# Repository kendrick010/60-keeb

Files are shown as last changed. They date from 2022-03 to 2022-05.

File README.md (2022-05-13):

# 60-keeb
> A 60% keyboard because why not.

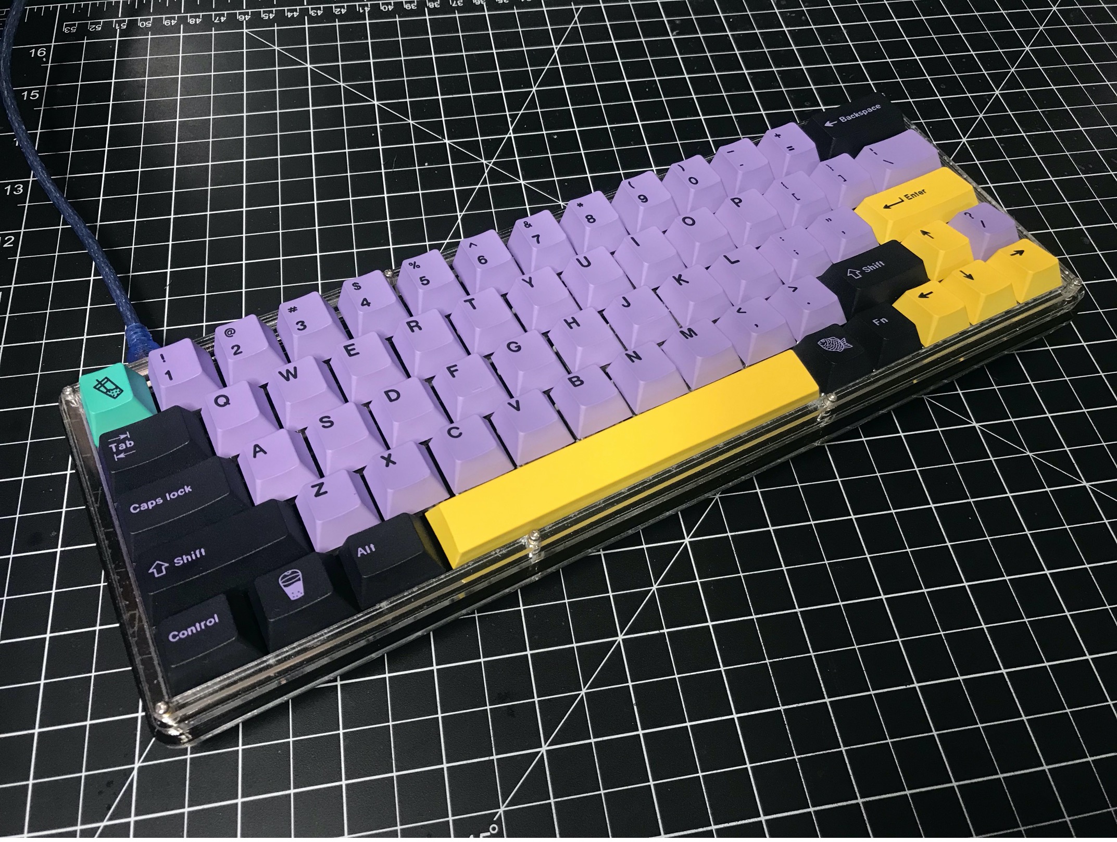
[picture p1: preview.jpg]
60-keeb


## How To...
Stack Order:
- plate_1 (top most)
- plate_2
- plate_3 (switch plate)
- plate_4
- plate_5
- plate_6 (bottom most)

## BOM
| Component | Vendor | Quantity|
| --- | --- | --- |
| PCB | -------- | 1 |
| ATMEGA32U4 | [Digikey](https://www.digikey.com/en/products/detail/microchip-technology/ATMEGA32U4RC-MUR/2507985) | 1 |
| USB Mini B Port | [Digikey](https://www.digikey.com/en/products/detail/edac-inc/690-005-299-043/4312191) | 1 |
| Tactile SMD Switch | [Digikey](https://www.digikey.com/en/products/detail/e-switch/TL3342F160QG-TR/379004) | 1 |
| 1N4148 SMD Diode | [Digikey](https://www.digikey.com/en/products/detail/smc-diode-solutions/1N4148WTR/6022450) | 63 |
| 16MHz SMD Cystal | [Digikey](https://www.digikey.com/en/products/detail/ecs-inc./ECS-160-12-33-AGM-TR/9648950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) | 1 |
| 22Ω SMD Resistor | [Digikey](https://www.digikey.com/en/products/detail/stackpole-electronics-inc/RMCF0805JT22R0/1942533) | 2 |
| 10kΩ SMD Resistor | [Digikey](https://www.digikey.com/en/products/detail/stackpole-electronics-inc/RMCF0805JT10K0/1942577) | 2 |
| 0.1uF Ceramic SMD Capacitor | [Digikey](https://www.digikey.com/en/products/detail/kyocera-avx/08055F104K4T2A/1024871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) | 4 |
| 1uF Ceramic SMD Capacitor | [Digikey](https://www.digikey.com/en/products/detail/yageo/CC0805KKX7R8BB105/2833621) | 1 |
| 4.7uF Ceramic SMD Capacitor | [Digikey](https://www.digikey.com/en/products/detail/samsung-electro-mechanics/CL21A475KAQNNNE/3886902) | 1 |
| 22pF Ceramic SMD Capacitor | [Digikey](https://www.digikey.com/en/products/detail/kemet/C0805C220J5GACTU/411388) | 2 |
| M2x16mm Standoffs | [Amazon](https://www.amazon.com/dp/B07768Q7YS?psc=1&ref=ppx_yo2ov_dt_b_product_details) | 8 |
| M2 Screws | [Amazon](https://www.amazon.com/dp/B07768Q7YS?psc=1&ref=ppx_yo2ov_dt_b_product_details) | 8 |

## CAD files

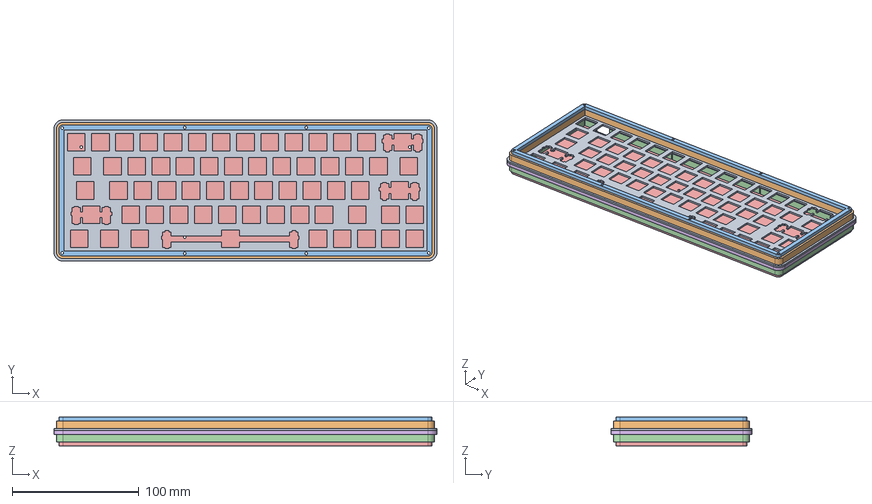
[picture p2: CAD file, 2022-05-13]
models/assembly.step
301.8 x 111.3 x 22.5 mm
plate_3
plate_2
plate_1
plate_5
plate_6
plate_4

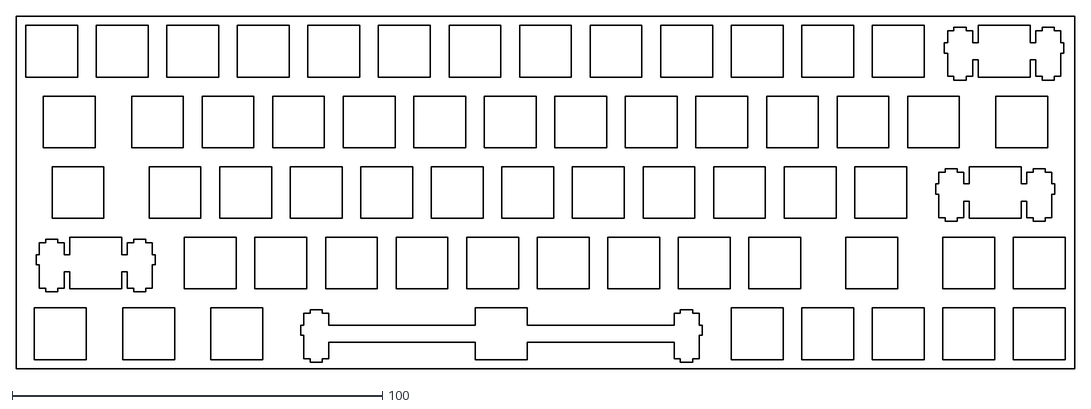
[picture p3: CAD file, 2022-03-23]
layout/60_layout.dxf
285.7 x 95.2

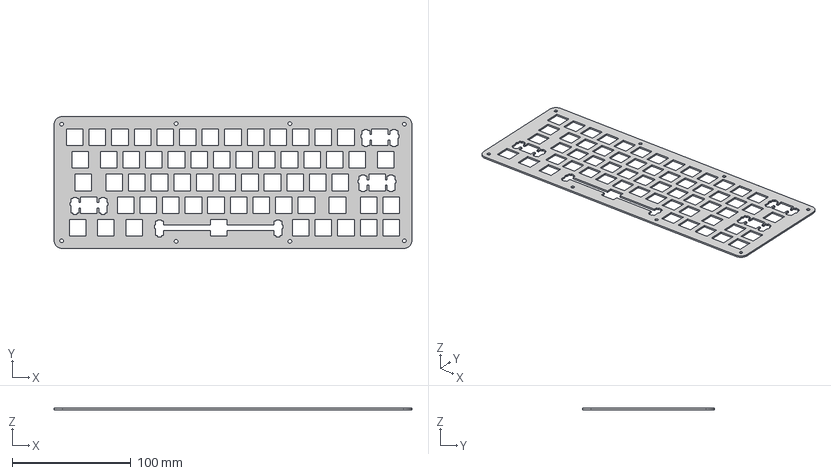
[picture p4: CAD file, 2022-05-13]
models/plate_3.step
301.7 x 111.2 x 1.50 mm

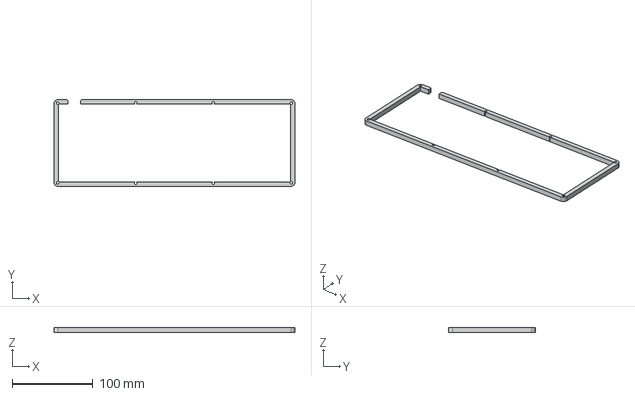
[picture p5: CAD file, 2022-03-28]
models/plate_5.step
297.8 x 107.2 x 6.00 mm

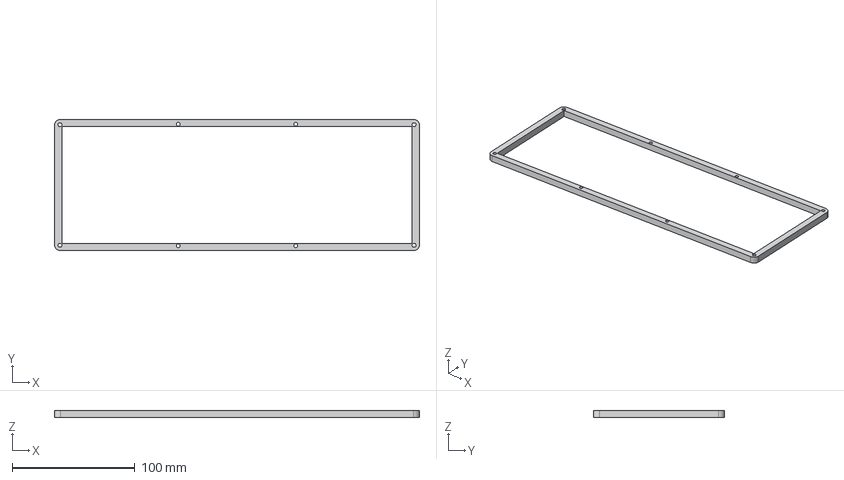
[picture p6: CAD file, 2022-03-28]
models/plate_2.step
297.8 x 107.2 x 6.00 mm

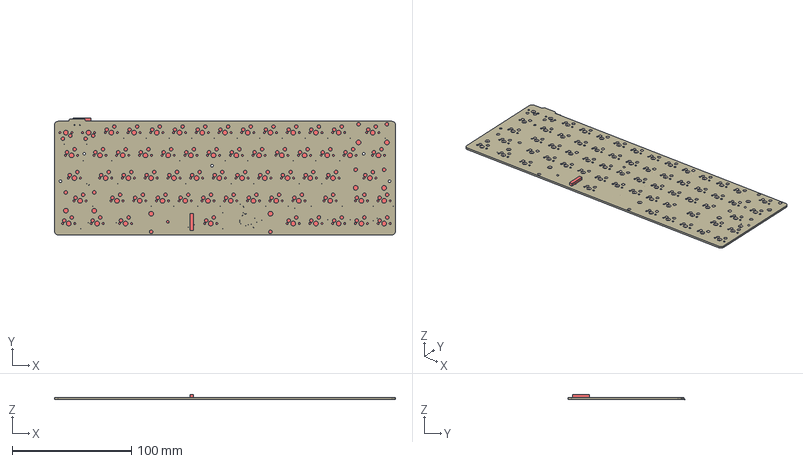
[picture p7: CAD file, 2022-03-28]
models/60_keyboard_PCB.step
285.8 x 97.9 x 4.24 mm
Board
1u
SOD-123 x 63
10k x 2
TACTILE
KEYSWITCH-PLAIN-MXHSPCB-1U x 59
KEYSWITCH-PLAIN-MXHSPCB-2U x 3
ATMEGA32U4
0.1u x 4
4.7u
22p x 2
CRYSTAL
KEYSWITCH-PLAIN-MXHSPCB-6.25U-FLIPPED
USB-CON
MA06-1

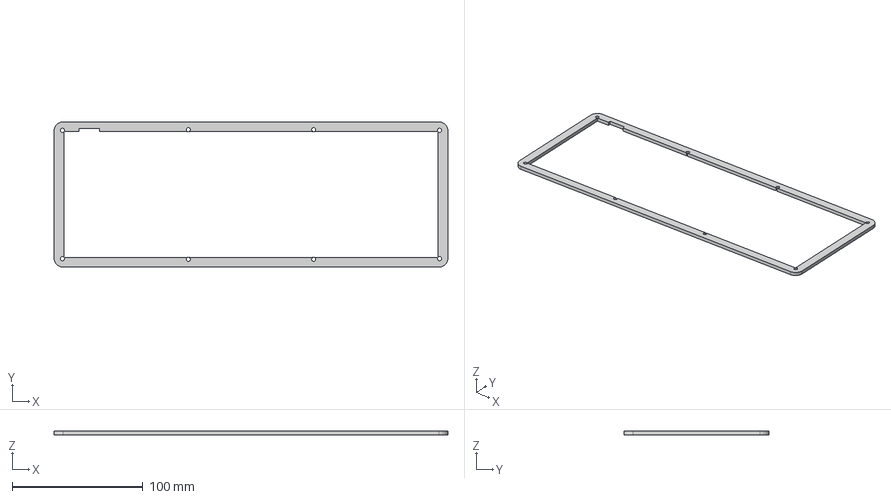
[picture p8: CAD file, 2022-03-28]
models/plate_4.step
301.8 x 111.2 x 3.00 mm

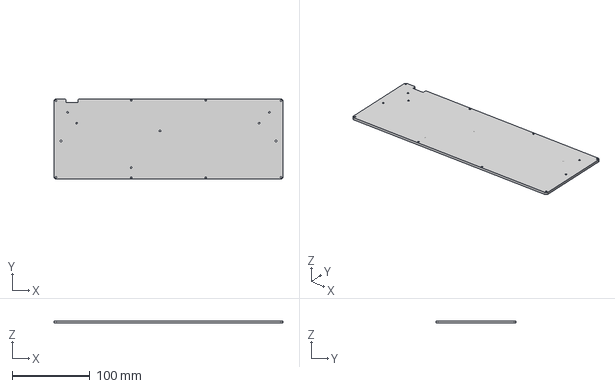
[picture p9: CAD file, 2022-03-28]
models/plate_6.step
293.8 x 103.3 x 3.00 mm

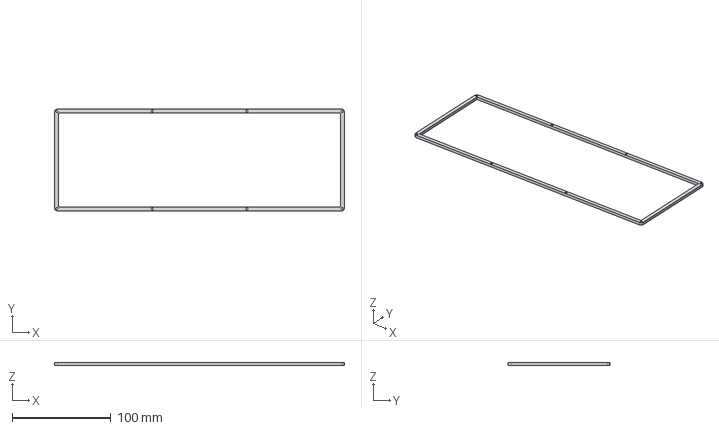
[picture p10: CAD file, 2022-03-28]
models/plate_1.step
293.8 x 103.3 x 3.00 mm

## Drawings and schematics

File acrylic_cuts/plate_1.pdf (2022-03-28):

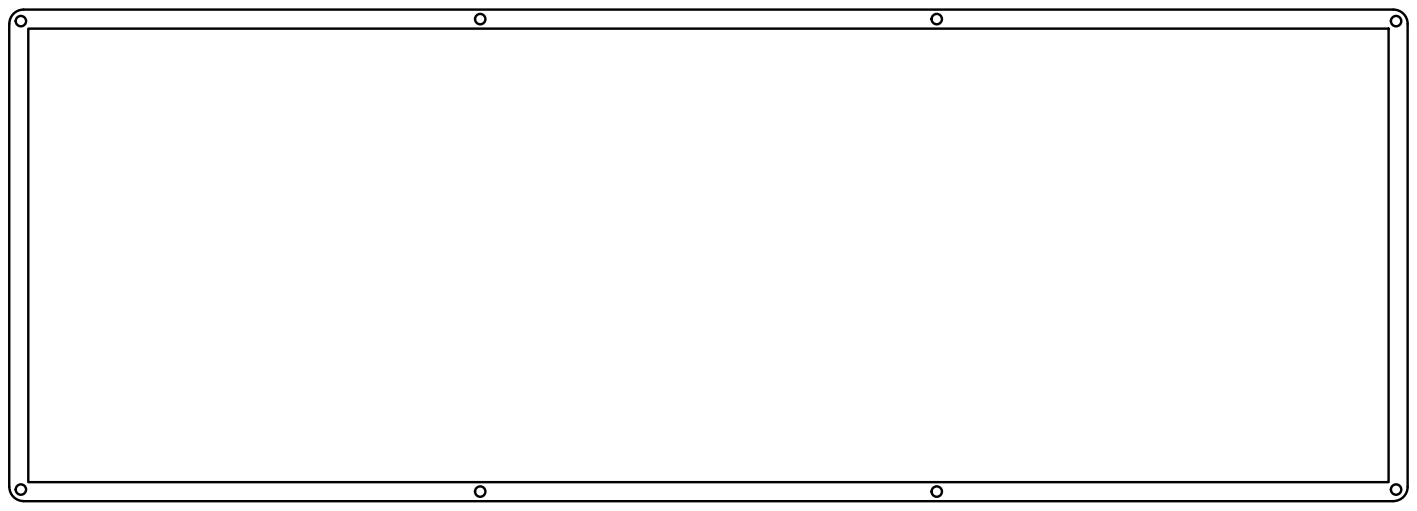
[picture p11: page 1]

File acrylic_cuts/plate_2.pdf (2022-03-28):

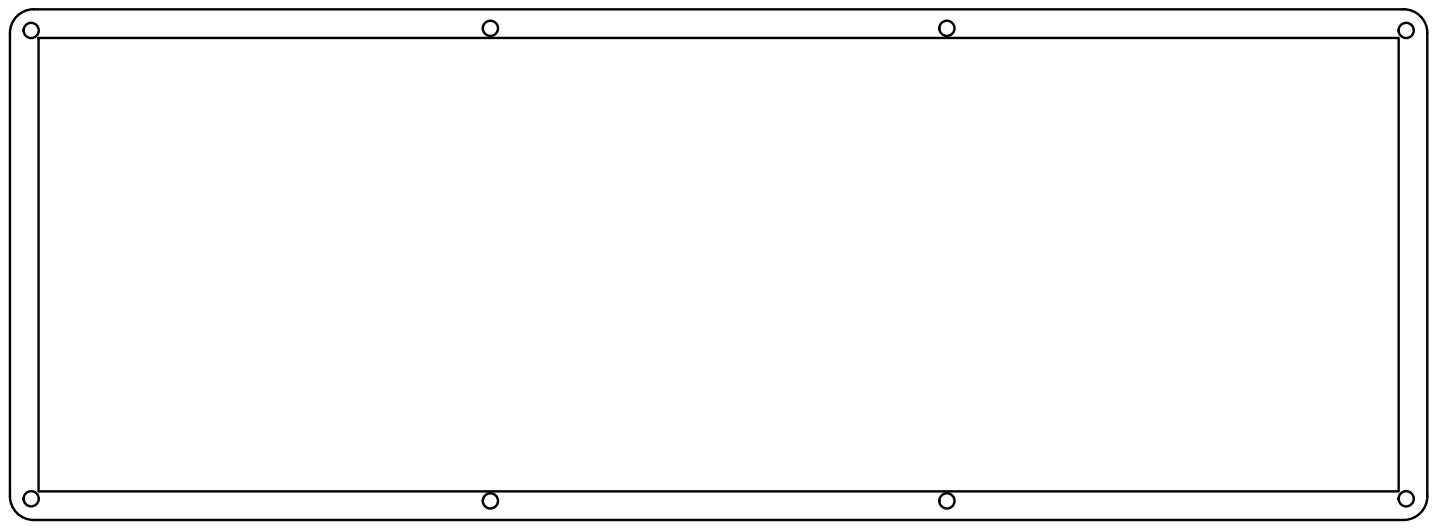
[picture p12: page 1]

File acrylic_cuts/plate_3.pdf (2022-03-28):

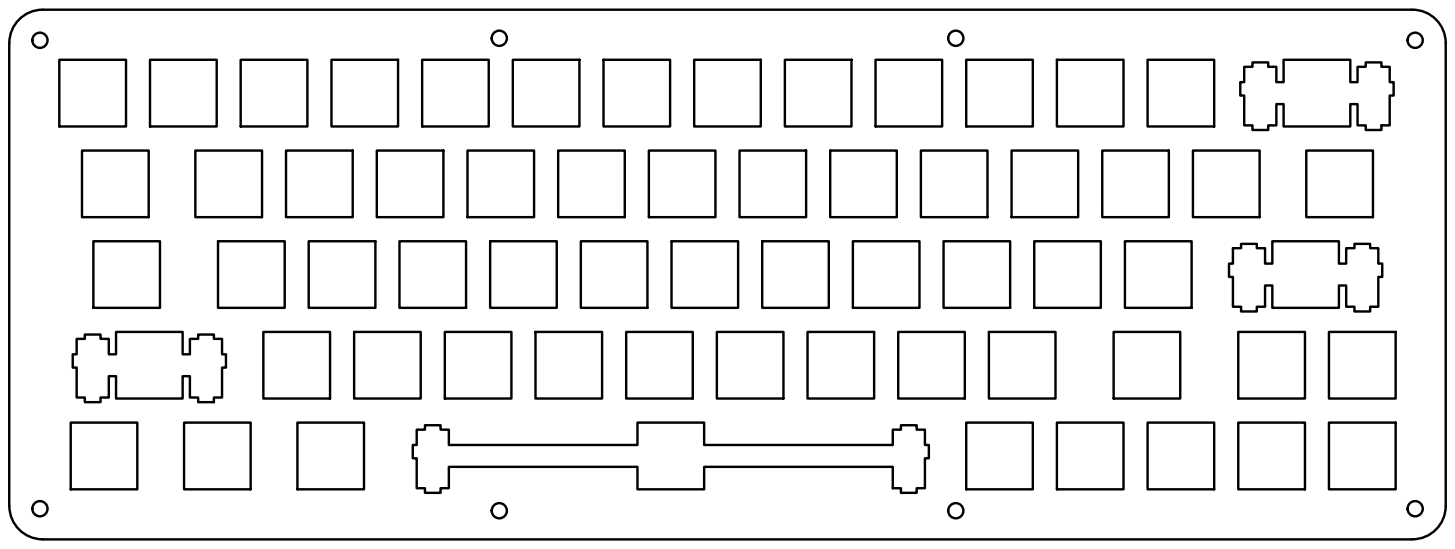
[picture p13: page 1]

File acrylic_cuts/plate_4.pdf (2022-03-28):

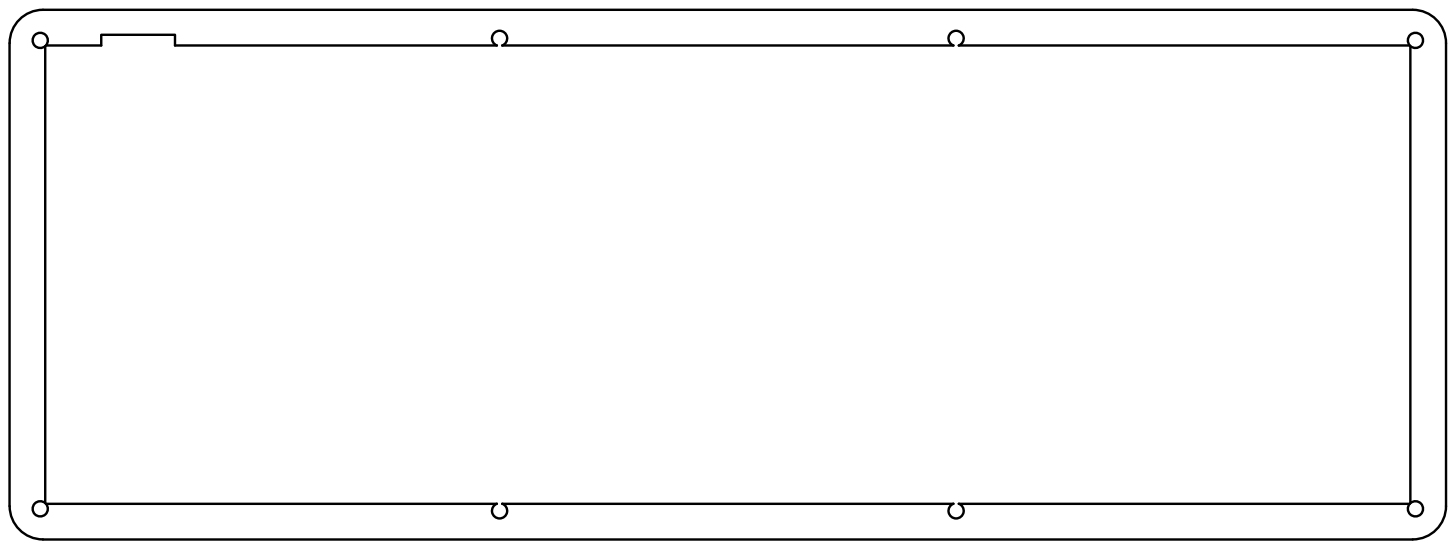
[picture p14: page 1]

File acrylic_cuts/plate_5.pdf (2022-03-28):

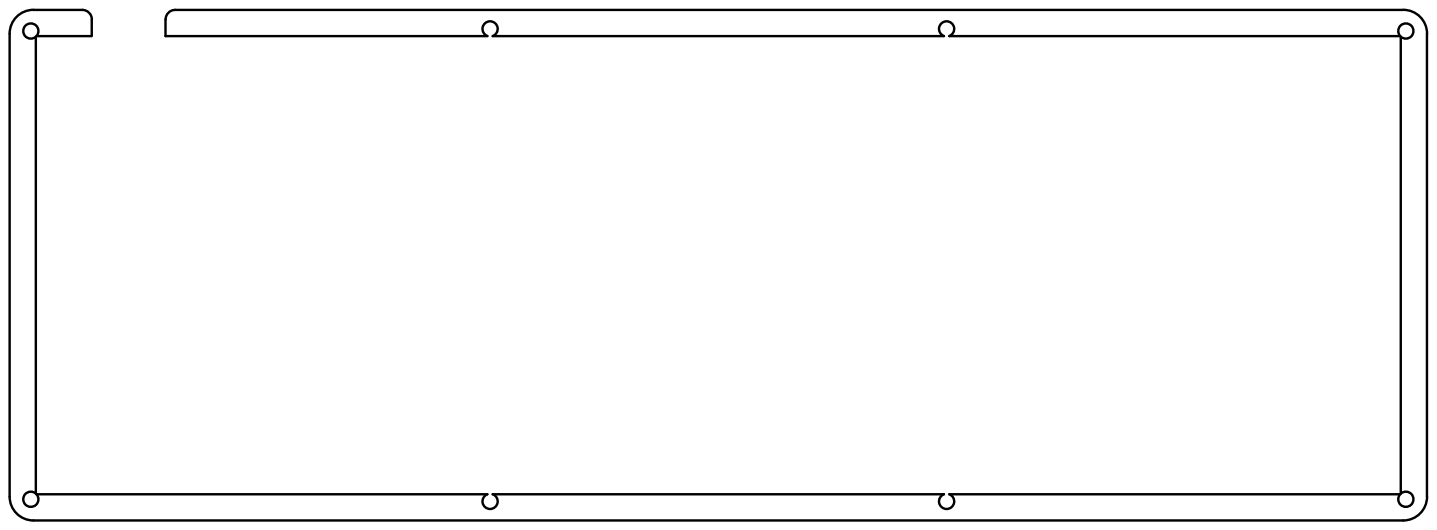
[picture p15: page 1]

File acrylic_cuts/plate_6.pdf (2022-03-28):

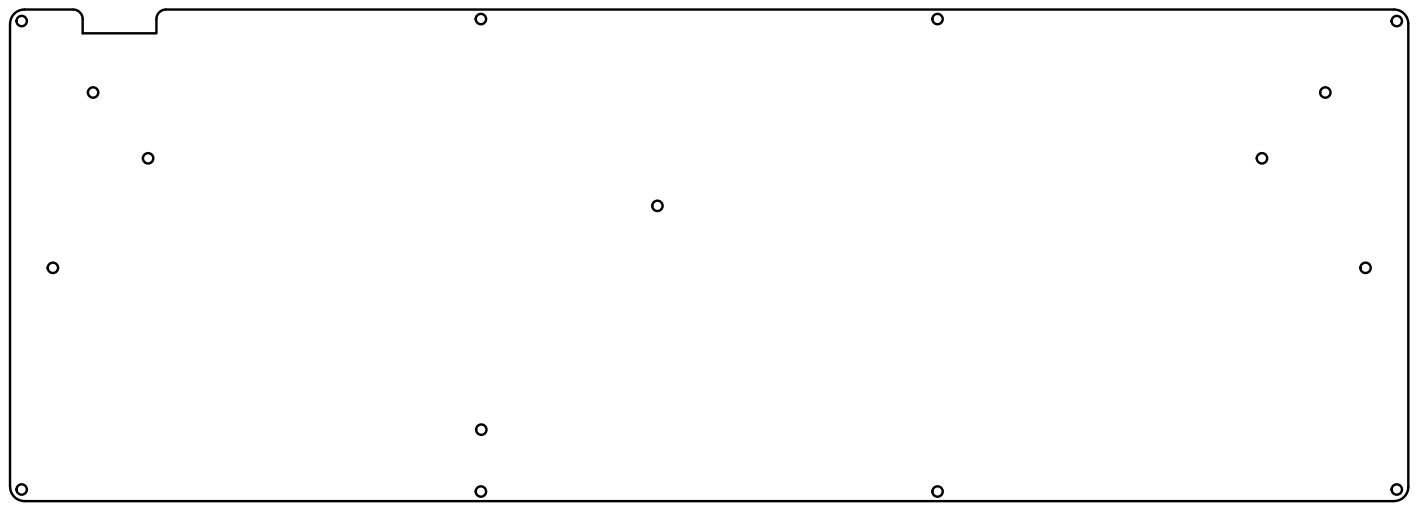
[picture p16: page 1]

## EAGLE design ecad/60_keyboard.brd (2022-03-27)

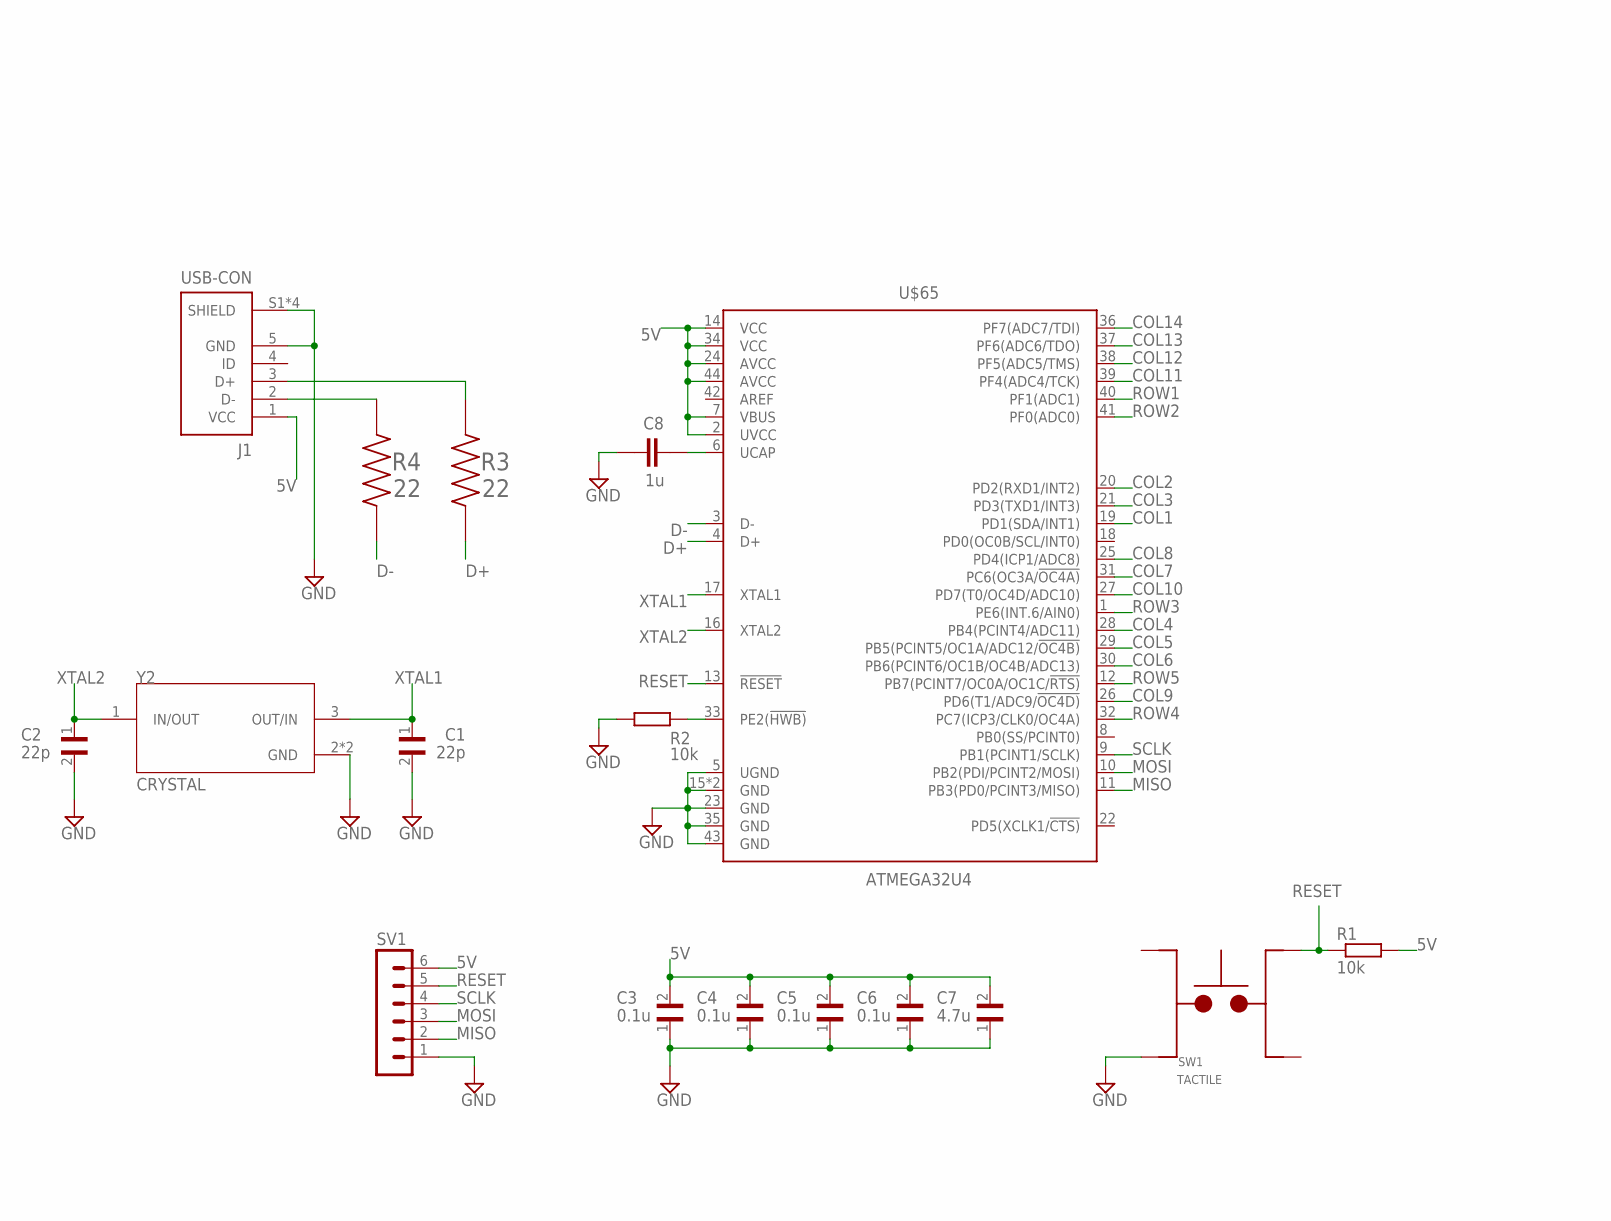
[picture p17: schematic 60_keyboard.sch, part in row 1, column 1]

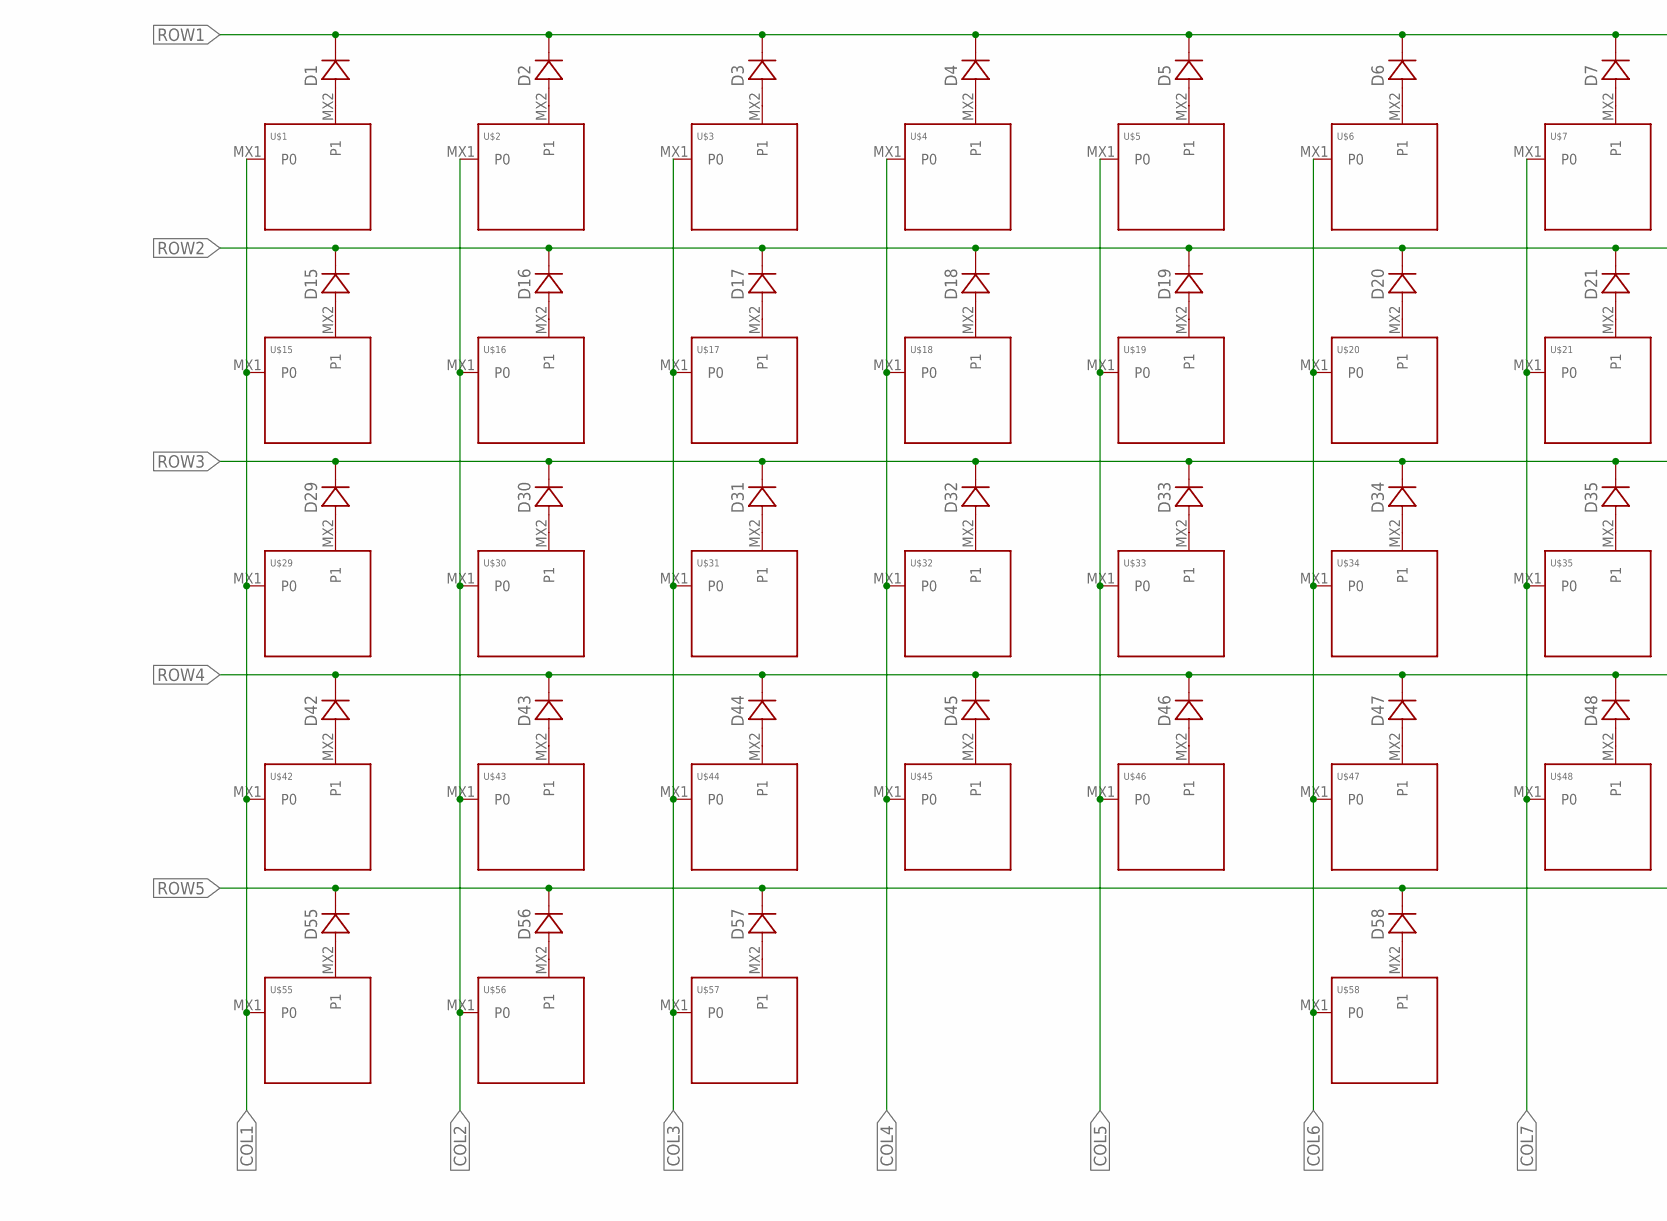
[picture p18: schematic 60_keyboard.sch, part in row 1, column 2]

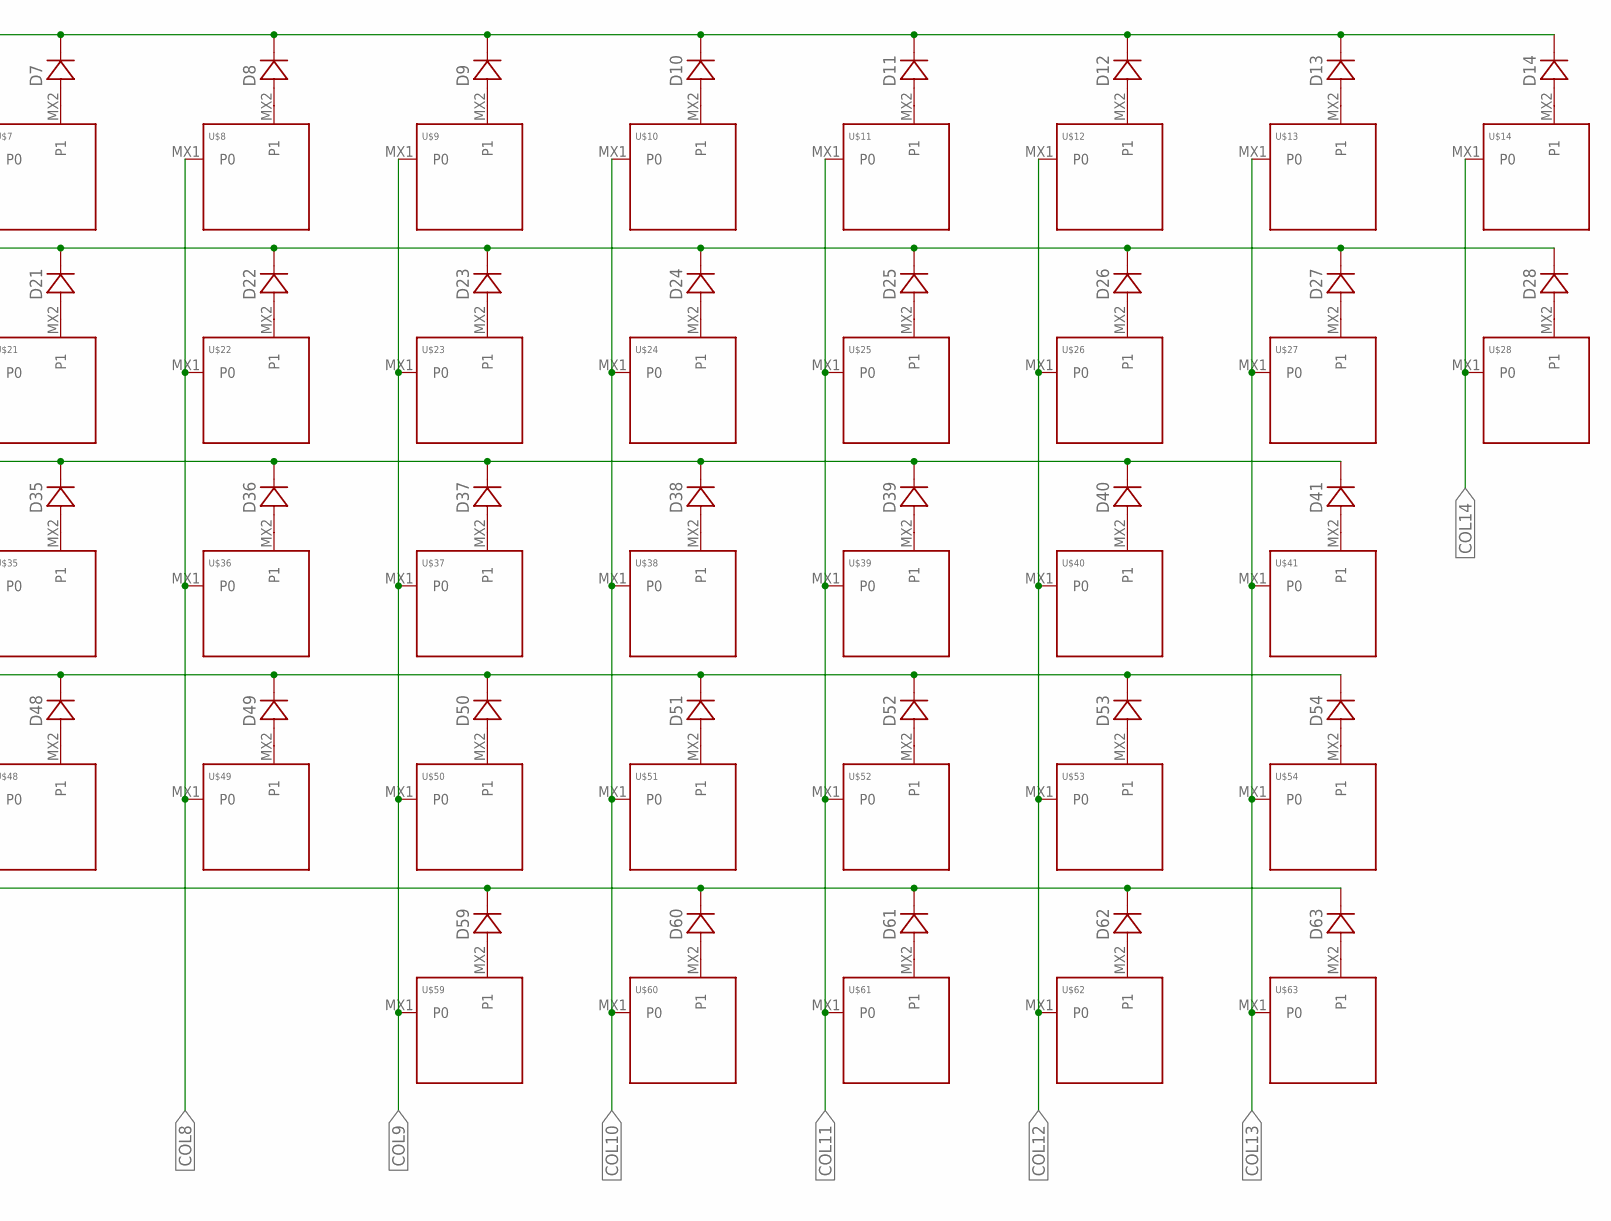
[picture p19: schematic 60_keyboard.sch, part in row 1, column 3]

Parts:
C1, C2: 22p; CAPC2012X140N
C3, C4, C5, C6: 0.1u; CAPC2012X140N
C7: 4.7u; CAPC2012X140N
C8: 1u; C0805
D1, D2, D3, D4, D5, D6, D7, D8, D9, D10, D11, D12, D13, D14, D15, D16, D17, D18, D19, D20, D21, D22, D23, D24, D25, D26, D27, D28, D29, D30, D31, D32, D33, D34, D35, D36, D37, D38, D39, D40, D41, D42, D43, D44, D45, D46, D47, D48, D49, D50, D51, D52, D53, D54, D55, D56, D57, D58, D59, D60, D61, D62, D63: DIODE-SOD-123; SOD-123
J1: USB-CON; EDAC_690-005-299-043
R1, R2: 10k; R0805
R3, R4: 22; RESC2012X65N
SV1: MA06-1
SW1: TACTILE; SW_TL3342F160QG/TR
U$1, U$2, U$3, U$4, U$5, U$6, U$7, U$8, U$9, U$10, U$11, U$12, U$13, U$15, U$16, U$17, U$18, U$19, U$20, U$21, U$22, U$23, U$24, U$25, U$26, U$27, U$28, U$29, U$30, U$31, U$32, U$33, U$34, U$35, U$36, U$37, U$38, U$39, U$40, U$43, U$44, U$45, U$46, U$47, U$48, U$49, U$50, U$51, U$52, U$53, U$54, U$55, U$56, U$57, U$59, U$60, U$61, U$62, U$63: KEYSWITCH-PLAIN-MXHSPCB-1U; MXHSPCB-1U
U$14, U$41, U$42: KEYSWITCH-PLAIN-MXHSPCB-2U; MXHSPCB-2U
U$58: KEYSWITCH-PLAIN-MXHSPCB-6.25U-FLIPPED; MXHSPCB-6.25U-FLIPPED
U$65: ATMEGA32U4; QFN-44
Y2: CRYSTAL; XTAL_ECS-160-12-33-AGN-TR

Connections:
5V: C3.2, C4.2, C5.2, C6.2, C7.2, J1.1 (VCC), R1.2, SV1.6, U$65.2 (UVCC), U$65.7 (VBUS), U$65.14 (VCC), U$65.24 (AVCC), U$65.34 (VCC), U$65.44 (AVCC)
COL1: U$1.MX1 (P0), U$15.MX1 (P0), U$29.MX1 (P0), U$42.MX1 (P0), U$55.MX1 (P0), U$65.19 (PD1(SDA/INT1))
COL2: U$2.MX1 (P0), U$16.MX1 (P0), U$30.MX1 (P0), U$43.MX1 (P0), U$56.MX1 (P0), U$65.20 (PD2(RXD1/INT2))
COL3: U$3.MX1 (P0), U$17.MX1 (P0), U$31.MX1 (P0), U$44.MX1 (P0), U$57.MX1 (P0), U$65.21 (PD3(TXD1/INT3))
COL4: U$4.MX1 (P0), U$18.MX1 (P0), U$32.MX1 (P0), U$45.MX1 (P0), U$65.28 (PB4(PCINT4/ADC11))
COL5: U$5.MX1 (P0), U$19.MX1 (P0), U$33.MX1 (P0), U$46.MX1 (P0), U$65.29 (PB5(PCINT5/OC1A/ADC12/!OC4B))
COL6: U$6.MX1 (P0), U$20.MX1 (P0), U$34.MX1 (P0), U$47.MX1 (P0), U$58.MX1 (P0), U$65.30 (PB6(PCINT6/OC1B/OC4B/ADC13))
COL7: U$7.MX1 (P0), U$21.MX1 (P0), U$35.MX1 (P0), U$48.MX1 (P0), U$65.31 (PC6(OC3A/!OC4A))
COL8: U$8.MX1 (P0), U$22.MX1 (P0), U$36.MX1 (P0), U$49.MX1 (P0), U$65.25 (PD4(ICP1/ADC8))
COL9: U$9.MX1 (P0), U$23.MX1 (P0), U$37.MX1 (P0), U$50.MX1 (P0), U$59.MX1 (P0), U$65.26 (PD6(T1/ADC9/!OC4D))
COL10: U$10.MX1 (P0), U$24.MX1 (P0), U$38.MX1 (P0), U$51.MX1 (P0), U$60.MX1 (P0), U$65.27 (PD7(T0/OC4D/ADC10))
COL11: U$11.MX1 (P0), U$25.MX1 (P0), U$39.MX1 (P0), U$52.MX1 (P0), U$61.MX1 (P0), U$65.39 (PF4(ADC4/TCK))
COL12: U$12.MX1 (P0), U$26.MX1 (P0), U$40.MX1 (P0), U$53.MX1 (P0), U$62.MX1 (P0), U$65.38 (PF5(ADC5/TMS))
COL13: U$13.MX1 (P0), U$27.MX1 (P0), U$41.MX1 (P0), U$54.MX1 (P0), U$63.MX1 (P0), U$65.37 (PF6(ADC6/TDO))
COL14: U$14.MX1 (P0), U$28.MX1 (P0), U$65.36 (PF7(ADC7/TDI))
D+: R3.1, U$65.4 (D+)
D-: R4.1, U$65.3 (D-)
GND: C1.2, C2.2, C3.1, C4.1, C5.1, C6.1, C7.1, C8.2, J1.5 (GND), J1.S1 (SHIELD), J1.S2 (SHIELD), J1.S3 (SHIELD), J1.S4 (SHIELD), R2.1, SV1.1, SW1.3, U$65.5 (UGND), U$65.15 (GND), U$65.23 (GND), U$65.35 (GND), U$65.43 (GND), U$65.TAB (GND), Y2.2 (GND), Y2.4 (GND)
MISO: SV1.2, U$65.11 (PB3(PD0/PCINT3/MISO))
MOSI: SV1.3, U$65.10 (PB2(PDI/PCINT2/MOSI))
unnamed: D1.A, U$1.MX2 (P1)
unnamed: D2.A, U$2.MX2 (P1)
unnamed: D3.A, U$3.MX2 (P1)
unnamed: D4.A, U$4.MX2 (P1)
unnamed: D5.A, U$5.MX2 (P1)
unnamed: D6.A, U$6.MX2 (P1)
unnamed: D7.A, U$7.MX2 (P1)
unnamed: D8.A, U$8.MX2 (P1)
unnamed: D9.A, U$9.MX2 (P1)
unnamed: D10.A, U$10.MX2 (P1)
unnamed: D11.A, U$11.MX2 (P1)
unnamed: D12.A, U$12.MX2 (P1)
unnamed: D13.A, U$13.MX2 (P1)
unnamed: D14.A, U$14.MX2 (P1)
unnamed: D15.A, U$15.MX2 (P1)
unnamed: D16.A, U$16.MX2 (P1)
unnamed: D17.A, U$17.MX2 (P1)
unnamed: D18.A, U$18.MX2 (P1)
unnamed: D19.A, U$19.MX2 (P1)
unnamed: D20.A, U$20.MX2 (P1)
unnamed: D21.A, U$21.MX2 (P1)
unnamed: D22.A, U$22.MX2 (P1)
unnamed: D23.A, U$23.MX2 (P1)
unnamed: D24.A, U$24.MX2 (P1)
unnamed: D25.A, U$25.MX2 (P1)
unnamed: D26.A, U$26.MX2 (P1)
unnamed: D27.A, U$27.MX2 (P1)
unnamed: D28.A, U$28.MX2 (P1)
unnamed: D29.A, U$29.MX2 (P1)
unnamed: D30.A, U$30.MX2 (P1)
unnamed: D31.A, U$31.MX2 (P1)
unnamed: D32.A, U$32.MX2 (P1)
unnamed: D33.A, U$33.MX2 (P1)
unnamed: D34.A, U$34.MX2 (P1)
unnamed: D35.A, U$35.MX2 (P1)
unnamed: D36.A, U$36.MX2 (P1)
unnamed: D37.A, U$37.MX2 (P1)
unnamed: D38.A, U$38.MX2 (P1)
unnamed: D39.A, U$39.MX2 (P1)
unnamed: D40.A, U$40.MX2 (P1)
unnamed: D41.A, U$41.MX2 (P1)
unnamed: D42.A, U$42.MX2 (P1)
unnamed: D43.A, U$43.MX2 (P1)
unnamed: D44.A, U$44.MX2 (P1)
unnamed: D45.A, U$45.MX2 (P1)
unnamed: D46.A, U$46.MX2 (P1)
unnamed: D47.A, U$47.MX2 (P1)
unnamed: D48.A, U$48.MX2 (P1)
unnamed: D49.A, U$49.MX2 (P1)
unnamed: D50.A, U$50.MX2 (P1)
unnamed: D51.A, U$51.MX2 (P1)
unnamed: D52.A, U$52.MX2 (P1)
unnamed: D53.A, U$53.MX2 (P1)
unnamed: D54.A, U$54.MX2 (P1)
unnamed: D58.A, U$58.MX2 (P1)
unnamed: D55.A, U$55.MX2 (P1)
unnamed: D56.A, U$56.MX2 (P1)
unnamed: D57.A, U$57.MX2 (P1)
unnamed: J1.2 (D-), R4.2
unnamed: D59.A, U$59.MX2 (P1)
unnamed: D60.A, U$60.MX2 (P1)
unnamed: D61.A, U$61.MX2 (P1)
unnamed: D62.A, U$62.MX2 (P1)
unnamed: D63.A, U$63.MX2 (P1)
unnamed: J1.3 (D+), R3.2
unnamed: R2.2, U$65.33 (PE2(!HWB))
unnamed: C8.1, U$65.6 (UCAP)
RESET: R1.1, SV1.5, SW1.2, U$65.13 (!RESET)
ROW1: D1.C, D2.C, D3.C, D4.C, D5.C, D6.C, D7.C, D8.C, D9.C, D10.C, D11.C, D12.C, D13.C, D14.C, U$65.40 (PF1(ADC1))
ROW2: D15.C, D16.C, D17.C, D18.C, D19.C, D20.C, D21.C, D22.C, D23.C, D24.C, D25.C, D26.C, D27.C, D28.C, U$65.41 (PF0(ADC0))
ROW3: D29.C, D30.C, D31.C, D32.C, D33.C, D34.C, D35.C, D36.C, D37.C, D38.C, D39.C, D40.C, D41.C, U$65.1 (PE6(INT.6/AIN0))
ROW4: D42.C, D43.C, D44.C, D45.C, D46.C, D47.C, D48.C, D49.C, D50.C, D51.C, D52.C, D53.C, D54.C, U$65.32 (PC7(ICP3/CLK0/OC4A))
ROW5: D55.C, D56.C, D57.C, D58.C, D59.C, D60.C, D61.C, D62.C, D63.C, U$65.12 (PB7(PCINT7/OC0A/OC1C/!RTS))
SCLK: SV1.4, U$65.9 (PB1(PCINT1/SCLK))
XTAL1: C1.1, U$65.17 (XTAL1), Y2.3 (OUT/IN)
XTAL2: C2.1, U$65.16 (XTAL2), Y2.1 (IN/OUT)

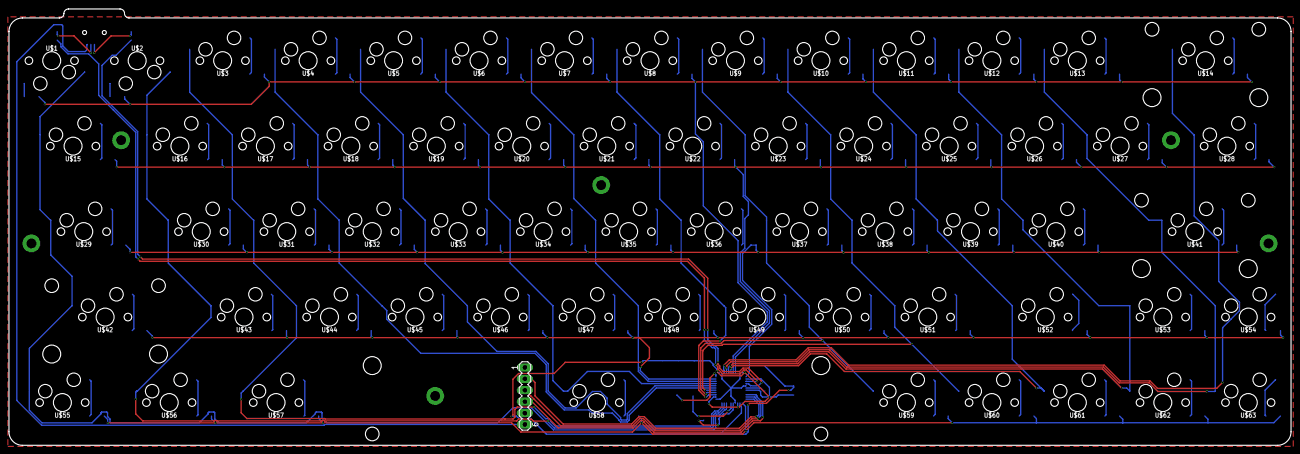
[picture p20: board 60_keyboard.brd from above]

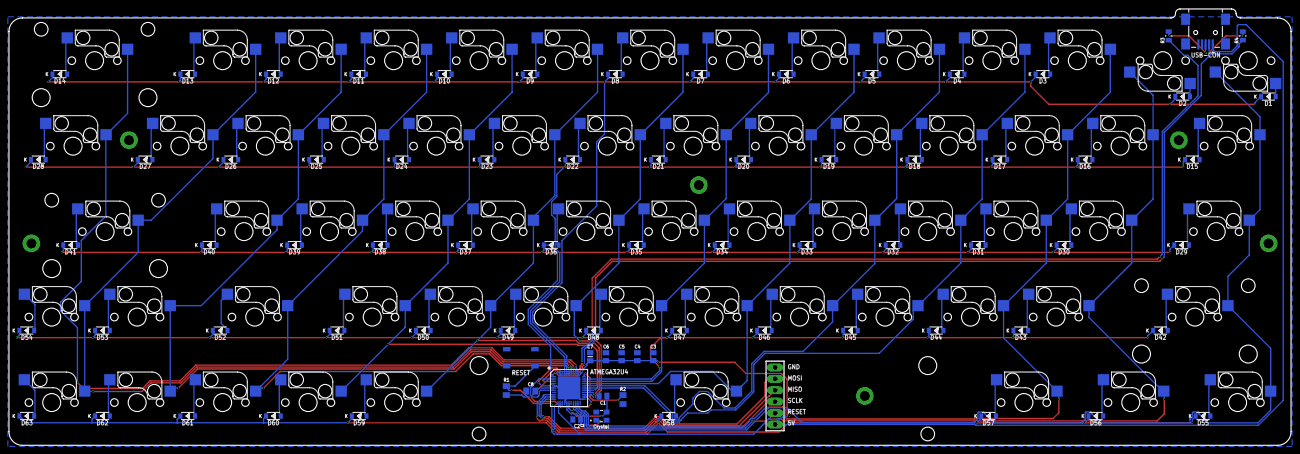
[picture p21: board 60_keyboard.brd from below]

Board: 2 copper layers, 285.8 x 97.2 mm, 143 parts (142 on the bottom side), 96 nets.

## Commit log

2021-12-13 updated layout
    [60_layout.dxf, BOM.xlsx]
2021-12-13 BOM removed
    [BOM.xlsx]
2021-12-16 case model and files
    [assembly.step, bottom_plate.step, bottom_support_plate.step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]
2022-03-23 new layout
    [60_layout.dxf]
2022-03-27 ecad, gebers
    [60_keyboard.brd, 60_keyboard.sch, 60_keyboard.step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]
2022-03-28 case files
    [60_keyboard.step, 60_keyboard_PCB.step, plate_1.step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]
2022-03-31 laser cut files
